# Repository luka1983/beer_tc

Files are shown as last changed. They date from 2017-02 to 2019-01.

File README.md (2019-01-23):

# Beer Temperature Control
This project uses Arduino Pro Mini ([Atmega328P](http://www.atmel.com/Images/Atmel-42735-8-bit-AVR-Microcontroller-ATmega328-328P_Datasheet.pdf))
board. However, all sources are provided in AVR native C.

The goal is to provide accurate fermentation chamber temperature control (within 0.1 degree celsius). Similar
to brew pi, the complete system contains AVR microcontroller board running control algorithm. The SW on board
implements serial terminal for controller configuration and state reading, but the ultimate goal is to create
stand alone controller configurable via digital input elements (push button + incremental encoder) while state
reading will be possible via i2c lcd screen.

Although sharing similar system architecture to [brew pi](https://github.com/BrewPi/), this project is
completely independent and created from scratch.

Until all hardware elements are in place, Atmega will be controlled with raspberry pi via serial interface

## Directory Structure

* web_server - Contains sources for web server and services running on it
* rpi - Contains sources of the raspberry pi
* src - Contains sources for the AVR

## Board documentation

Board documentation can be found [here](https://www.arduino.cc/en/Main/arduinoBoardProMini).

Here is also direct link to [pdf schematics](https://www.arduino.cc/en/uploads/Main/Arduino-Pro-Mini-schematic.pdf).

## Installation

### Web Server

Installing SW on web server goes down to:

 - installing web page
 - installing handler for messages

To install web page, copy server_software/web_server contents into /var/www/html/beer to your favourite server.

To install handler for messages, copy server_software/apps/beermon_handler.py to server and try to run it.

It is possible you'll need some additional SW. To install necessary SW, execute (at least):

```
sudo apt-get update
sudo apt-get install python python3 mosquitto mosquitto-clients python-mosquitto python3-pip python-pip -y
sudo pip3 install paho-mqtt
sudo pip2 install paho-mqtt
```

After this, make sure your firewall is configured to receive on 1883

Once beermon_handler.py works, you can proceed with service installation. Copy beermon.service:

```
sudo cp beermon.service /etc/systemd/system/
sudo systemctl enable beermon.service
sudo systemctl start beermon
```

### RPi Software

RPi part is installed by executing rpi/beermon-rpi.py on rpi startup. For detailed instructions, check instructions within rpi sw directory.

## AVR Toolchain

These instruction assume that either USBasp or buspirate AVR programmer with avrdude are used for device programming.

### Windows
Install following tools

* [avr toolchain](http://www.atmel.com/tools/atmelavrtoolchainforwindows.aspx)
* [gnu make](http://fab.cba.mit.edu/classes/4.140/doc/projects/ftsmin/make-3.81.exe)
* [avrdude](http://fab.cba.mit.edu/classes/4.140/doc/projects/ftsmin/avrdude-win-64bit.zip)

and configure your PATH variable.

### Linux

Here will be given Linux instructions.

Install required packages:

sudo apt-get install avr-libc avrdude binutils-avr gcc-avr srecord

## Interfacing programmer

### Buspirate 3.6

| Buspirate | Arduino Pro Mini |
|---|---|
| GND | GND |
| +5V or +3V3 | Vcc |
| CS | RESET |
| MOSI | MOSI (11) |
| MISO | MISO (12) |
| SCLK,CLK | SCK (13) |

## Building and downloading
Clone the repo, build the sources with _make_, and push _hex_ file
to board with following command.

### usbasp

```
$ avrdude -c usbasp -p m328p -u -U flash:w:beer_tc.hex
```

### buspirate:

Before any operations, learn port of the buspirate and set it:

```
port=/dev/ttyUSB0
```

To program device, execute:

```
sudo avrdude -c buspirate -P $port -p m328p -u -U flash:w:bin/beer_tc.hex
```

To power atmega from buspirate, execute:

```
echo "m 2 " > $port;echo "W" > $port
```

## Command set
When beer_tc is running on AVR board, the following commands can be issued via serial interface. all
commands are terminated with new line character.

### Get commands
Get commands come in following form

        get <object>

and the response is formated requested object type. The list of retrievable objects as well as belonging
types are given in following table.

Format for requesting is "get <object>\n", where response does not contain any newline characters.

### Set commands
Set commands come in following form.

        set <object> <value>

If execution is successful, command returns _ok_. If not the command fail reason string is returned.

### Command objects
While _get_ command is supported for all listed objects, only some can be updated with _set_ command.

| object | type | r/w | description | status |
|:---:|---|-----|---|---|
| ts | decimal | rw  | controller set temperature | a |
| t1 | decimal | ro  | temperature reading for 1st sensor | a |
| t2 | decimal | ro  | temperature reading for 2nd sensor | a |
| ct | integer | rw  | control loop discretization time (ms) | n/a |
| cd | integer | rw  | output state change cooldown interval (ms) | n/a |
| un | string | rw  | unit system in use, i for imperial, m for metric | n/a |
| fw | string | ro  | firmware version | n/a |
| id | string | ro  | board id | a |

## Working with LCD

LCD connection is described in hw/lcd/lcd-to-atmega.pdf. As a sample project one can use beer_tc with LCD_DEMO defined in beer_tc.c

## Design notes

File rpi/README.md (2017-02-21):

# Beermon for Raspberry pi

This script serves as a control interface to the temperature
controller. Its task is to read current temperature, and
possibily other sensors, and send output via mqtt to the
predefined server. This part runs automatically and doesn't
need user's intervention.

The other part is setting certain values to the controller,
e.g. temperature. This is done via mqtt interface. For latest
topic names and messages, check the script. Here are current
configurable values:

 * beermon_config/ts - get/set controller's temperature

To interface with setting/getting use mqtt. To check last value,
subscribe to the topic/variable, e.g.:

```
$ mosquitto_sub -t beermon_config/ts
```

To query current value, send '?' to topic/variable:

```
$ mosquitto_pub -t beermon_config/ts -m "?"

$ mosquitto_sub -t beermon_config/ts
```

To set variable, send value to the topic/variable

```
$ mosquitto_pub -t beermon_config/ts -m "18.5"
```

## Installing the script in general

At the moment, script is started automatically on rpi by managment
sw from previous project. It can also be started via systemd, check
web_server for template if needed.

Requirements for the script are:

```
$ sudo apt-get update
$ sudo apt-get install python python3 mosquitto mosquitto-clients python-mosquitto python3-pip python-pip -y
$ sudo pip3 install paho-mqtt
$ sudo pip2 install paho-mqtt
$ sudo pip2 install pyserial
$ sudo pip3 install pyserial
```

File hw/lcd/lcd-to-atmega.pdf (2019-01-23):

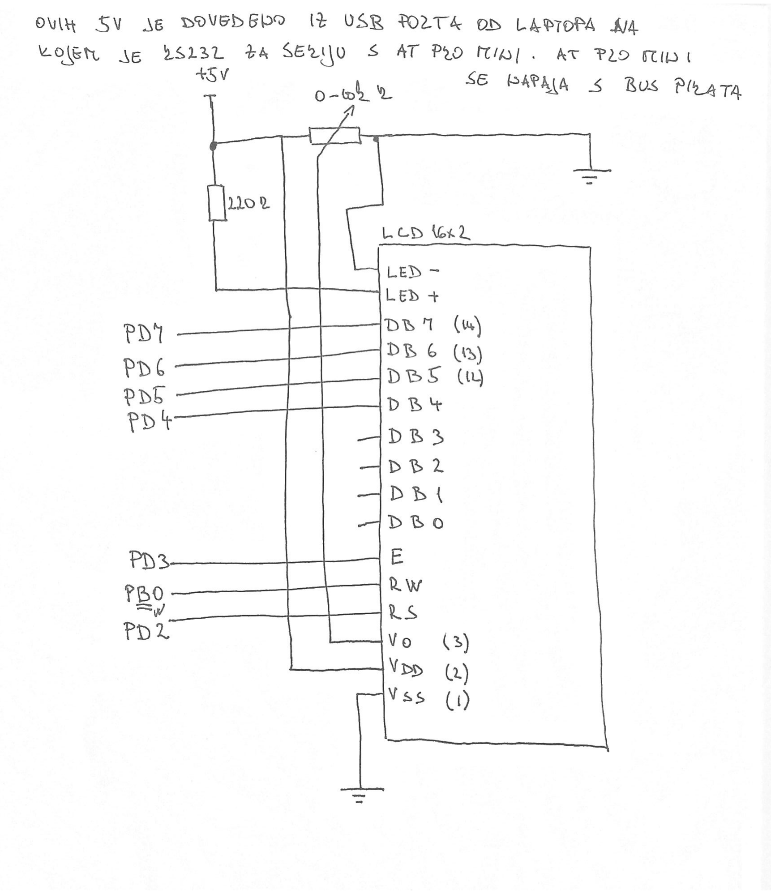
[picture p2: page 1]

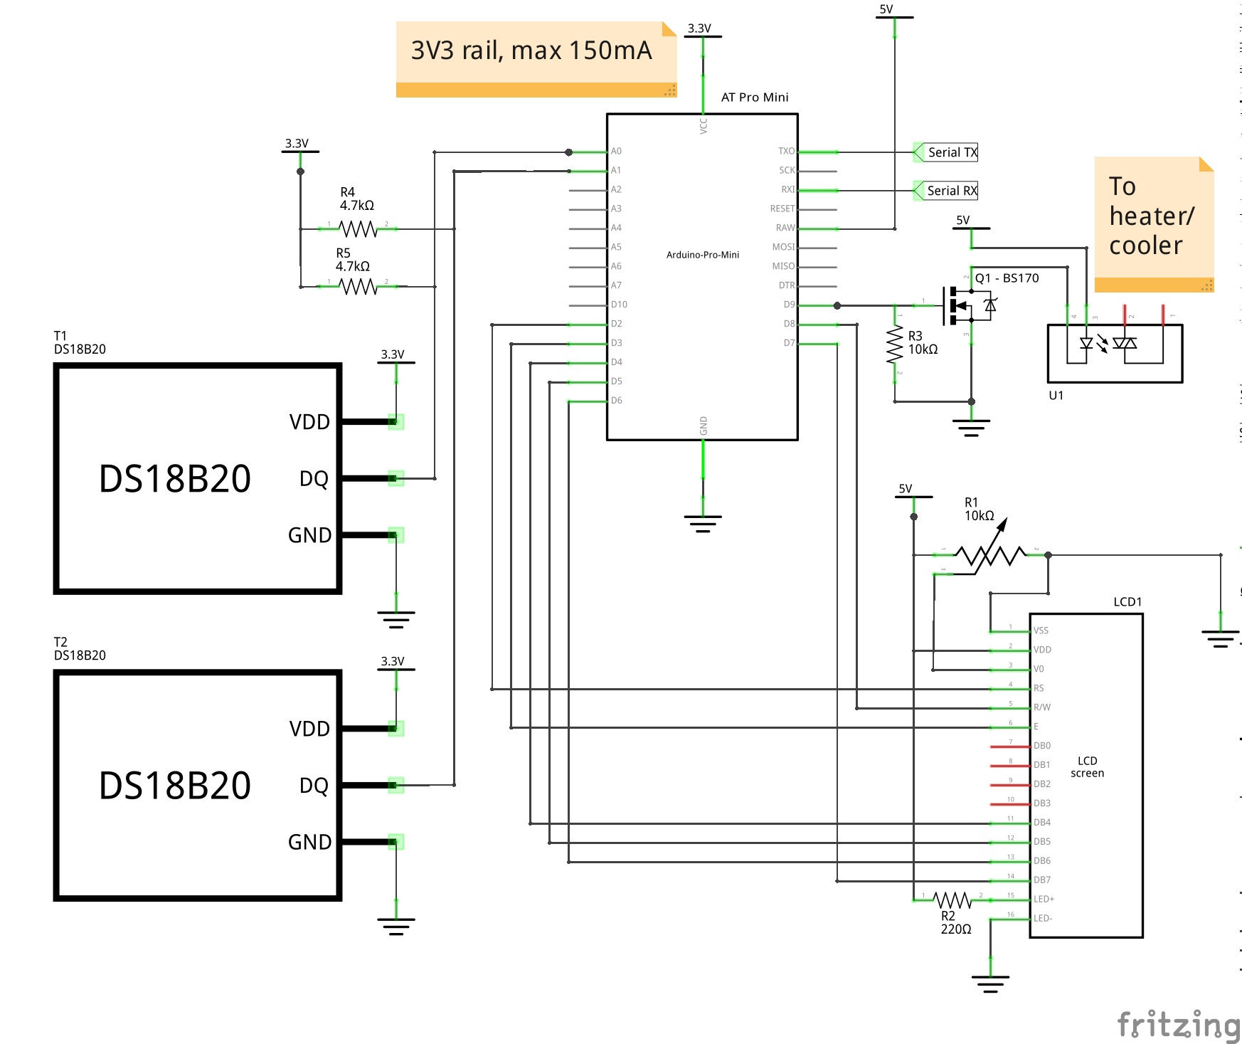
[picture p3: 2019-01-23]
hw/proto-2/beer-tc-proto-2.png

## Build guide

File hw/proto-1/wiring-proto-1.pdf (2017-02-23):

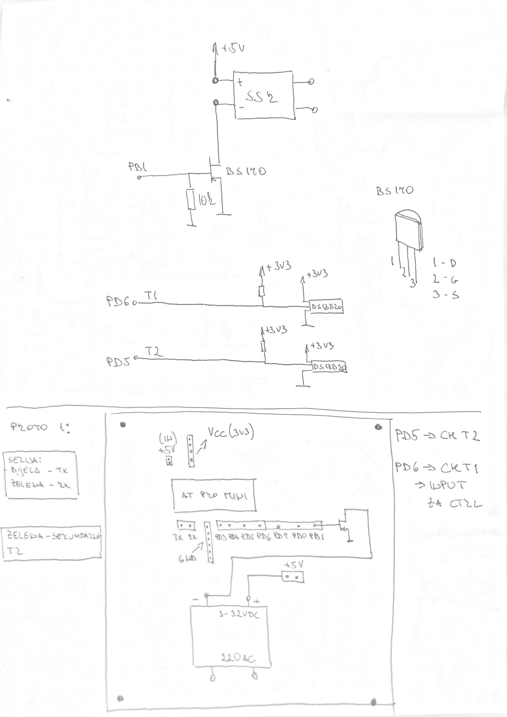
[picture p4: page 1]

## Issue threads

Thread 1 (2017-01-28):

Temperature sensor reading

luka1983, 2017-01-28:
Temperature reading from 1-wire sensor ds18b20 - code architecture and implementation.

matijaGP, 2017-02-14:
I've added avr-ds18b20-lib branch, and demo code for reading temperature sensor, notably, this commit is of interest: b013d352b0e397ed7159e6550c3e9e7ef46019f1

Should we add reading of the temperature in tcontrol.c ?

luka1983, 2017-02-14:
Yes, and I also think it makes sense to have temp sensor read implemented as a separate module (e.g. tread.h/c). So we just need this module to expose single reading func e.g. uint16_t get_temp_read() or something like that.

luka1983, 2017-02-14:
We should also implement temperature read via interrupt. The small problem here is that we're already using 16-bit timer for temperature control loop, so getting 1s with 8-bit will require some local counter also.

The other possibility  is to trigger new sensor read when temperature is read by control loop, and just return the reading triggered from previous request.

matijaGP, 2017-02-14:
Ok

matijaGP, 2017-02-14:
Why not read temperature in the control loop itself?

luka1983, 2017-02-14:
I just thought that it would be neat to have these processes in separate threads, but there is probably no real need for this, and your solution is also cleaner. That was also the second possibility I've mentioned above.

Closed 2017-02-21.

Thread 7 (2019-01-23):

DEC_DIV should be defined in tcontrol.h

matijaGP, 2019-01-23:
While getting ts, I noticed that ts is stored as integer in tcontrol, while divider for it is in commands.h. Seems a bit wrong, Luka, could you check it? Maybe I'm missing something something, but I think that commands and control are tightly coupled

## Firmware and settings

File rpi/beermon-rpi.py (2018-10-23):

#!/usr/bin/env python3

import syslog
import random
import datetime
import time
import threading
import array
import fcntl
import re
import subprocess
import os
import pwd
import sys
import shlex
import shutil
import paho.mqtt.client as mqtt
import paho.mqtt.publish as publish
import stat
from collections import deque
import serial
from serial.tools import list_ports

# Remote mqtt broker address
MQTT_HOST="52.28.77.176"
MQTT_HOST_PORT=1883

# Local mqtt broker address
MQTT_LOCAL_HOST="localhost"
MQTT_LOCAL_PORT=1883

# Sensors read period, in seconds
sensor_read_period = 60

# Sensor list
sensors = ['t1', 't2', 'ts', 'co']

# configuration topic name - this is the name of the topic for
# configuration values. e.g. CONFIG_TOPIC/ts
CONFIG_TOPIC="beermon_config"

# Minimum and maximum temperature values
MIN_TEMP=5
MAX_TEMP=30

# Baud rate of the controller
BAUD_RATE=19200

# Supported board ids
supported_sensors_id = ['123456', 'tca']

# Max retries to try to read controller
max_retries = 3

def msg_queue_worker():
    msg_worker_period = 30
    message_backoff_tmo = 5

    print("Starting message queue worker, worker period = %d, backoff = %d"
            %(msg_worker_period, message_backoff_tmo))

    syslog.syslog(syslog.LOG_INFO, "Starting message queue worker, worker period = %d, backoff = %d"
            %(msg_worker_period, message_backoff_tmo))


    while True:
        try:
            message = message_queue.popleft()
        except IndexError as err:
            # Empty queueu
            time.sleep(msg_worker_period)
            continue

        if not isinstance(message[0], str) or not isinstance(message[1], str):
            print("message_worker: Found invalid message in queue " + str(message))
            syslog.syslog(syslog.LOG_INFO, "message_worker: Found invalid message in queue " + str(message))
            time.sleep(msg_worker_period)
            continue

        print("message_worker: Found message in the queue, sending")
        syslog.syslog(syslog.LOG_INFO, "message_worker: Found message in the queue, sending")

        retval = send_message_to_server(message[1], message[0], 0)
        if retval != 0:
            message_queue.appendleft(message)
        else:
            # Sleep a bit, dont storm all mqtt messages to the server
            time.sleep(message_backoff_tmo)
            continue

        time.sleep(msg_worker_period)

'''
Sends mqtt message to MQTT_HOST
If message fails to be sent, it will be queued for later sending
    message - Full message to send
    topic   - topic to which to sent
    queueu  - if message fails, queue it to the message queue, default True
'''
def send_message_to_server(message, topic, queue=1):
    try:
        publish.single(topic, message, hostname=MQTT_HOST, port=MQTT_HOST_PORT, qos=1)
    except Exception as err:
        print("Exception %r while sending message {%s}, queue = %d" %(err, "[" + topic + "]" + message, queue))
        syslog.syslog(syslog.LOG_INFO, "Exception %r while sending message {%s}, queue = %d" %(err, "[" + topic + "]" + message, queue))
        if queue == 1:
            print("Appending previous message to the message queue")
            syslog.syslog(syslog.LOG_INFO, "Appending previous message to the message queue")
            message_queue.append([topic, message])
        return -1
    return 0


def send_message_local(message, topic):
    print("sending local message: [" + topic + "]" + message)
    syslog.syslog(syslog.LOG_INFO, "sending local message: [" + topic + "]" + message)
    try:
        publish.single(topic, message, hostname=MQTT_LOCAL_HOST, port=MQTT_LOCAL_PORT, qos=1, retain=False)
    except Exception as err:
        print("Exception %r while sending message {%s}" %(err, "[" + topic + "]" + message))
        syslog.syslog(syslog.LOG_INFO, "Exception %r while sending message {%s}" %(err, "[" + topic + "]" + message))
        return -1
    return 0

'''
Function sends command over serial and reads
back result. This function is thread safe

Function returns string with response or 'NOK' if
execution did not finished correctly
'''
def send_over_serial_read_result(command):
    with lock:
        command = command + "\n"
        try:
            ser.write(command.encode())
        except Exception as err:
            print("Got %r while writing command '%s' to serial port" %(err,command))
            syslog.syslog(syslog.LOG_INFO, "Got %r while writing command '%s' to serial port" %(err,command))
            return "NOK"
        try:
            line = ser.readline()
        except Exception as err:
            print("Got %r while reading command '%s' output from serial port" %(err,command))
            syslog.syslog(syslog.LOG_INFO, "Got %r while reading command '%s' output from serial port" %(err,command))
            return "NOK"

        return line.decode(encoding="utf-8", errors="ignore")

'''
Function returns true if string s is representation
of float
'''
def is_float(s):
    try:
        float(s)
    except ValueError:
        return False
    return True

'''
Function reads sensor from global interface and
returns string formatted as decimal value. Function
throws ValueError in case result obtained is not
decimal value.
Function will try to read max_attempts prior returning
failure.
'''
def read_sensor(sensor, max_attempts = max_retries):
    for i in range(0, max_retries):
        value = send_over_serial_read_result("get " + sensor) 
        if is_float(value):
            return value
        else:
            time.sleep(1)
            continue
    raise ValueError("Response is not decimal, communication FAILED!")

'''
Function writes command via global interface to the controller
and returns True if write was OK, or false if it wasnt.
Function will try to write max_attempts prior returning
failure.
'''
def write_controller(command, max_attempts = max_retries):
    for i in range(0, max_retries):
        response = send_over_serial_read_result(command) 
        if response == "ok":
            return True
        else:
            continue
    return False

'''
Function checks whether sensor is supported by the script
'''
def check_sensor_id(sensor_id):
    if sensor_id in supported_sensors_id:
        return True
    return False

def process_message(topic, text):
    print("Processing message: [%s] %s" %(topic, text))
    syslog.syslog(syslog.LOG_INFO, "Processing message: [%s] %s" %(topic, text))
    variable = topic.split('/')[-1]
    value = text
    if variable == "ts":
        if value == "?":
            curr_ts = read_sensor("ts")
            send_message_local(curr_ts, CONFIG_TOPIC + "/ts")
        else:
            if not is_float(value):
                print("Value to be set not recognized as float <%s>" %(value,))
                syslog.syslog(syslog.LOG_ERR, "Value to be set not recognized as float <%s>" %(value,))
                return
            ret = send_over_serial_read_result("set ts " + value) 
            print("Set %s with %s, retval = %s" %(variable, value, ret))
            syslog.syslog(syslog.LOG_INFO, "Setting %s with %s, retval = %s" %(variable, value, ret))
            # Refresh retained value and notify listeners
            # send_message_local(value, CONFIG_TOPIC + "/ts")

def beermon_handler_on_connect(client, userdata, rc):
    print("Connected with result code "+str(rc))
    syslog.syslog(syslog.LOG_INFO, "Connected with result code "+str(rc))
    print("Subscribing to " + CONFIG_TOPIC + "/# topic")
    syslog.syslog(syslog.LOG_INFO, "Subscribing to " + CONFIG_TOPIC + "/# topic")
    client.subscribe(CONFIG_TOPIC + "/#")

def beermon_handler_on_message(client, userdata, msg):
    text = msg.payload.decode(encoding="utf-8", errors="ignore")
    process_message(msg.topic, text)

'''
Function iterates over all comports and tries to discover on which
port is controller connected
'''
def discover_controller():
    ports = list_ports.comports()
    for i in range(0, max_retries):
        for comport in ports:
            print("[%d] probing %s" %(i, comport.device))
            syslog.syslog(syslog.LOG_INFO, "[%d] probing %s" %(i, comport.device))
            try:
                with serial.Serial(comport.device, BAUD_RATE, timeout=2, write_timeout=2) as ser:
                    command = "get id\n"
                    try:
                        ser.write(command.encode())
                    except Exception as err:
                        print("Got %r while writing command to serial port" %(err,))
                        syslog.syslog(syslog.LOG_INFO, "Got %r while writing command to serial port" %(err,))
                        continue
                    try:
                        line = ser.readline()
                    except Exception as err:
                        print("Got %r while reading command output from serial port" %(err,))
                        syslog.syslog(syslog.LOG_INFO, "Got %r while reading command output from serial port" %(err,))
                        continue
                controller_id = line.decode(encoding="utf-8", errors="ignore")
                print("[%d] %s: response to 'get id': '%s'" %(i, comport.device, controller_id))
                syslog.syslog(syslog.LOG_INFO, "[%d] %s: response to 'get id': '%s'" %(i, comport.device, controller_id))
                if check_sensor_id(controller_id):
                    print("[%d] %s: found controller, id = %s" %(i, comport.device, controller_id))
                    syslog.syslog(syslog.LOG_INFO, "[%d] %s: found controller, id = %s" %(i, comport.device, controller_id))
                    return comport.device
            except Exception as err:
                print("[%d] While opening serial port %s, %r occured" %(i, comport, err))
                syslog.syslog(syslog.LOG_INFO, "[%d] While opening serial port %s, %r occured" %(i, comport, err))
                # Give time to system to settle down, e.g. udev rules might still be firing
                time.sleep(5)

    return None

'''
function raises alarm
'''
def alarm(topic, message):
    publish.single("alarm/" + topic, message)

'''
Function reads inital ts and publishes it.
This should be called prior subscribing to the topic
for setting/getting values for ts due to reatin used there.
'''
def set_initial_ts():
    try:
        value = read_sensor("ts")
    except ValueError as err:
        return False
    send_message_local(value, CONFIG_TOPIC + "/ts")
    return True

if __name__ == "__main__":

    debug = False

    print("Starting %s, debug is %s" %(os.path.basename(__file__), str(debug)))
    syslog.syslog(syslog.LOG_INFO, "Starting %s, debug is %s" %(os.path.basename(__file__), str(debug)))

    lock = threading.Lock()

    port = discover_controller()
    #port = "/dev/ttyUSB1"
    if port is None:
        print("Failed to discover controller")
        syslog.syslog(syslog.LOG_INFO, "Failed to discover controller")
        alarm("tctr", "Failed to discover controller")
        print("Exiting due to previous errors")
        syslog.syslog(syslog.LOG_INFO, "Exiting due to previous errors")
        sys.exit(1)

    ser = serial.Serial(port, BAUD_RATE, timeout=1, write_timeout=1)

    # Global variable for mqtt unsent message queue
    message_queue = deque(maxlen = 20000)

    msg_queue_thread = threading.Thread(target=msg_queue_worker,
                        name = "msg_queue_worker", args=())
    msg_queue_thread.setDaemon(True)
    msg_queue_thread.start()

    beermon_handler = mqtt.Client()
    beermon_handler.on_connect = beermon_handler_on_connect
    beermon_handler.on_message = beermon_handler_on_message
    beermon_handler.connect(MQTT_LOCAL_HOST, MQTT_LOCAL_PORT, 60)
    beermon_handler.loop_start()

    sens_errors = dict()
    for sensor in sensors:
        sens_errors[sensor] = 0

    while True:
        for sensor in sensors:
            try:
                value = read_sensor(sensor)
            except ValueError as err:
                sens_errors[sensor] = sens_errors[sensor] + 1
                print("FAILED to read sensor %s, errors %d" %(sensor, sens_errors[sensor]))
                syslog.syslog(syslog.LOG_INFO, "FAILED to read sensor %s, errors %d" %(sensor, sens_errors[sensor]))
                alarm("tctr", "FAILED to read sensor %s, errors %d" %(sensor, sens_errors[sensor]))
                print("Exiting due to previous errors")
                syslog.syslog(syslog.LOG_INFO, "Exiting due to previous errors")
                sys.exit(1)
            date = datetime.datetime.now()
            if date.second < 30:
                date = date.replace(second = 0)
            else:
                date = date.replace(second = 30)
            date_s = date.strftime("%Y-%m-%d %H:%M:%S")
            message = str(date_s) + "," + value
            print("Sending %s: %s" %(sensor, message))
            syslog.syslog(syslog.LOG_INFO, "Sending %s: %s" %(sensor, message))
            if debug:
                print("Debug - not sending")
                syslog.syslog(syslog.LOG_INFO, "Debug - not sending")
            else:
                send_message_to_server(message, "beermon/" + sensor)
        time.sleep(sensor_read_period)

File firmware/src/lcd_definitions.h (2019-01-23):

#define	LCD_IO_MODE	1
#define	LCD_PORT	PORTD
#define	LCD_DATA0_PORT	LCD_PORT
#define	LCD_DATA1_PORT	LCD_PORT
#define	LCD_DATA2_PORT	LCD_PORT
#define	LCD_DATA3_PORT	LCD_PORT
#define	LCD_DATA0_PIN	4
#define	LCD_DATA1_PIN	5
#define	LCD_DATA2_PIN	6
#define	LCD_DATA3_PIN	7
#define	LCD_RS_PORT	LCD_PORT
#define	LCD_RS_PIN	2
#define	LCD_RW_PORT	PORTB
#define	LCD_RW_PIN	0
#define	LCD_E_PORT	LCD_PORT
#define	LCD_E_PIN	3

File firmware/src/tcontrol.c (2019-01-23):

#include <avr/io.h>
#include <avr/interrupt.h>
#include <avr/eeprom.h>
#include "serial.h"
#include "tcontrol.h"
#include "commands.h"

uint32_t EEMEM ts_eeprom;
uint32_t EEMEM _ts_eeprom;

static struct TempController tc = {
	.ct = 1000,
	// Although ts is set below, set default
	// value to something sensible, just in
	// case that init function is not ran
	.ts = 16 * DEC_DIV,
	.hl = 5 * DEC_DIV / 10,
	.hu = 5 * DEC_DIV / 10,
	.t1 = NULL,
	.t2 = NULL,
	.state = Stopped,
	.out = {
		.port = &PORTB,
		.dirreg = &DDRB,
		.num = 1,
		.dir = Out,
		.active = High,
		.init = Off
	},
	.cdc = 0,
	.cdt = 10000
};

static struct Pin led = {
	.port = &PORTB,
	.dirreg = &DDRB,
	.num = 5,
	.dir = Out,
	.active = High,
	.init = On
};

int32_t get_ts() {
	return tc.ts;
}

uint8_t set_ts(int32_t ts) {
	uint32_t eeprom_val, _eeprom_val;
	if (ts == tc.ts)
		return 0;
	eeprom_val = ts;
	_eeprom_val = ~ts;
	eeprom_update_dword(&ts_eeprom, eeprom_val);
	eeprom_update_dword(&_ts_eeprom, _eeprom_val);
	tc.ts = ts;
	return 0;
}

int32_t get_t1() {
	return tc.t1->temp_c;
}

int32_t get_t2() {
	return tc.t2->temp_c;
}

int32_t get_co() {
	return pin_state(tc.out) == On ? 1 : 0;
}

void init_ts_from_eeprom(void)
{
	uint32_t eeprom_val, _eeprom_val;

	eeprom_val = eeprom_read_dword(&ts_eeprom);
	_eeprom_val = eeprom_read_dword(&_ts_eeprom);

	// Protection against non-inited eeprom
	// Value, along with mirrored value is stored
	// If those do not match, set default value
	if (eeprom_val == ~_eeprom_val)
		tc.ts = eeprom_val;
	else
		tc.ts = 17 * DEC_DIV;
}

void init_control_loop(uint32_t ct) {
	tc.ct = ct;

	// Initialize ts from eeprom
	init_ts_from_eeprom();

	// controller digital output init
	pin_init(tc.out);

	// led pin init_cl
	pin_init(led);

	// read temperature channel configuration
	tc.t1 = temperature_get_channel_by_name("t1");
	tc.t2 = temperature_get_channel_by_name("t2");

	// command interface initialization
	set_command_handler(GetTs, &get_ts);
	set_command_handler(SetTs, &set_ts);
	set_command_handler(GetT1, &get_t1);
	set_command_handler(GetT2, &get_t2);
	set_command_handler(GetCo, &get_co);

	// command loop interrupt initialization
	TCCR1B |= (1 << WGM12);					// CTC mode on OCR1A match
	TIMSK1 |= (1 << OCIE1A);				// Trigger int on compare match

	// Cmp register value for tc in ms => OCR1A = tc * (f_cpu / 1000) / prescaler.
	// For atmega328p max prescaler value is 1024 meaning max achievable tc in ms
	// is 1024 * 2^16 / F_CPU i.e. 4194ms with F_CPU = 16MHz
	OCR1A = (uint16_t)(ct * (F_CPU / 1000) / 1024);

	return;
}

void start_control_loop() {
	tc.state = Started;
	tc.cdc = tc.cdt * tc.ct;
	TCCR1B |= (1 << CS10) | (1 << CS12);	// Set prescaler (starts timer)
	return;
}

void stop_control_loop() {
	tc.state = Stopped;
	TCCR1B &= ~((1 << CS10) | (1 << CS12));
	return;
}

void set_control_out(PinState out) {
	tc.cdc = 0;
	// inverted output
	if (out == On)
		pin_on(tc.out);
	else if (out == Off)
		pin_off(tc.out);
}

void update_control_timers() {
	tc.cdc++;
	return;
}

void update_temperature_readings() {
	temperature_read(tc.t1, 1);
	temperature_read(tc.t2, 1);
	tc.t1->temp_c = DEC_DIV * tc.t1->temp_raw / tc.t1->result_multiplier;
	tc.t2->temp_c = DEC_DIV * tc.t2->temp_raw / tc.t2->result_multiplier;
}

void update_controller() {
	update_control_timers();
	if (tc.cdc < tc.cdt / tc.ct) return;
	if ((tc.t1->temp_c > tc.ts + tc.hu) && pin_state(tc.out) == Off)
		set_control_out(On);
	else if ((tc.t1->temp_c < tc.ts - tc.hl) && pin_state(tc.out) == On)
		set_control_out(Off);
}

void update_control_loop() {
	update_temperature_readings();

	switch (tc.state) {
		case Stopped:
		case Err:
			break;
		case Started:
			tc.state = Initializing;
			break;
		case Initializing:
			tc.state = Running;
			break;
		case Running:
			update_controller();
	}
	return;
}

ISR(TIMER1_COMPA_vect) {
	// temperature control code here
	pin_toggle(led);
	update_control_loop();
}

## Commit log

2017-02-01 Add connection interface between board and buspirate
2017-02-02 variardic formated serial print
2017-02-14 Add demo code for reading DS18B20 sensor
    To make use of this code, connect DS18B20 to PIND6. External PULL UP is
    needed as well (~5K)
2017-02-14 Add unit for reading temperature
    for details and usage, see temperature.h
2017-02-14 Add demo code for new temperature unit
2017-02-14 Use values from temperature sensor channel
2017-02-14 Initial version of beermon service
    beermon service is in charge of handling incoming messages and
    storing them where web server can process them
2017-02-14 Add rpi software
    This software runs on rpi. Its aim is to read Atmega and send messages
    to the server with sensor data
2017-02-16 Add set temperature to graph
2017-02-16 Improve example for temperature reading
2017-02-16 Add one more temperature sensor to config
2017-02-19 temperature readings integrated with controller, some code refactoring, some new commands implemented
2017-02-20 Make board id something unique
    Later, we should put this to be string, e.g. tca
2017-02-20 Change sensor name to ts instead of set
2017-02-20 Exit in case sensor cannot be read
    It is possible that serial port was reseted, so just exit and let
    managment to deal with the situation
    [beermon-rpi.py]
2017-02-20 Add logging to the syslog as well
    This is actually WA for two issues which are related to the rpi platform being used.
    Those will eventually get fixed, but for now, log to both stdout and systemd logger
    [beermon-rpi.py]
2017-02-21 Adapt driver pin for current assembly
2017-02-21 Do not send update of ts
    This will cause loop in which update will refresh current state.
    The whole retain should just be dropped
2017-02-21 Set sample period of sensors to 30 secs
2017-02-21 Round timestamps to 0/30 secs
    Google graphs have problem that when agregating data, one has to have
    data point for each timestamp (or whatever is on apcisa). Force this
    by forcing seconds to be either 30 or 0
    [beermon-rpi.py]
2017-02-21 Take into account seconds as well
    When creating date, seconds were rounded so agregated graphs do not have discontinuitis. This
    broke situation when sample rate was less then 1 minute
2017-02-21 Remove retain from interface to SET
    This makes more problems than sense. It will also play bad with setting manually
    via buttons and encoder. Just remove retainining and whole managment for it
    [beermon-rpi.py]
2017-02-21 gpio initial state support, controller initialization period -> no output till initial temperature reading is being retrieved
2017-02-21 controller cooldown timer to make sure no jerky control output is possible
2017-02-23 Add wiring diagram for proto-1 board
2017-02-27 Display control output with the temperatures
    It is anywy interesting to see them side by side. Later this can be changed for
    dual y charts:
    https://developers.google.com/chart/interactive/docs/gallery/linechart#dual-y-charts
2017-03-28 Remove debug prints
2017-03-30 Add debug print how much points we display per graph
    This is useful debug option to get feeling how much we can go with
    To use it, check dev console in browser.
2018-10-23 rpi: Increase sensor read to 60 seconds
    Sensors are read and sent every 30 seconds. This is
    too much for display loop, increase to 60 seconds.
    [beermon-rpi.py]
2018-10-23 Switch to highcharts graph framework
    Highcharts are superior to google charts, switch to it.
2018-10-28 Highcharts: Set correct format for x axis
    Highcharts needs timestamp in miliseconds since 1970
2019-01-23 sensors: Change pins where temperature sensors are connected
    PORTD is needed for LCD. Move temperature sensors to
    PC0 (t1 - control input) and PC1 (t2 - free sensor).
2019-01-23 temperature api: Clear up what async read means
2019-01-23 lcd_update_ts: Fix compiler warning
    Fix:
    beer_tc.c: In function ‘lcd_update_ts’:
    beer_tc.c:54:6: warning: unused variable ‘err’ [-Wunused-variable]
    int err = 0;
2019-01-23 ts: Make T set (ts) persistent
    ts needs to survive resets. Use eeprom to achieve so.
    [tcontrol.c]
2019-01-23 proto-2: Add HW schematics
    Add hw schematics for proto-2. Inputs are still missing
2019-01-23 lcd: Fix ts display
    Temperatures above 33 were wrongly displayed, fix variables
    types
2019-02-14 hw: Add source for the schematic and reference to the tool
    [beer-tc-final.fzz]
